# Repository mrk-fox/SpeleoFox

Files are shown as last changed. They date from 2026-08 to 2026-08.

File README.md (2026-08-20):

<div align="center">
<h1>SpeleoFox</h1><br>
  
A Speleology headlamp - engineered for the caves 

 


<br>

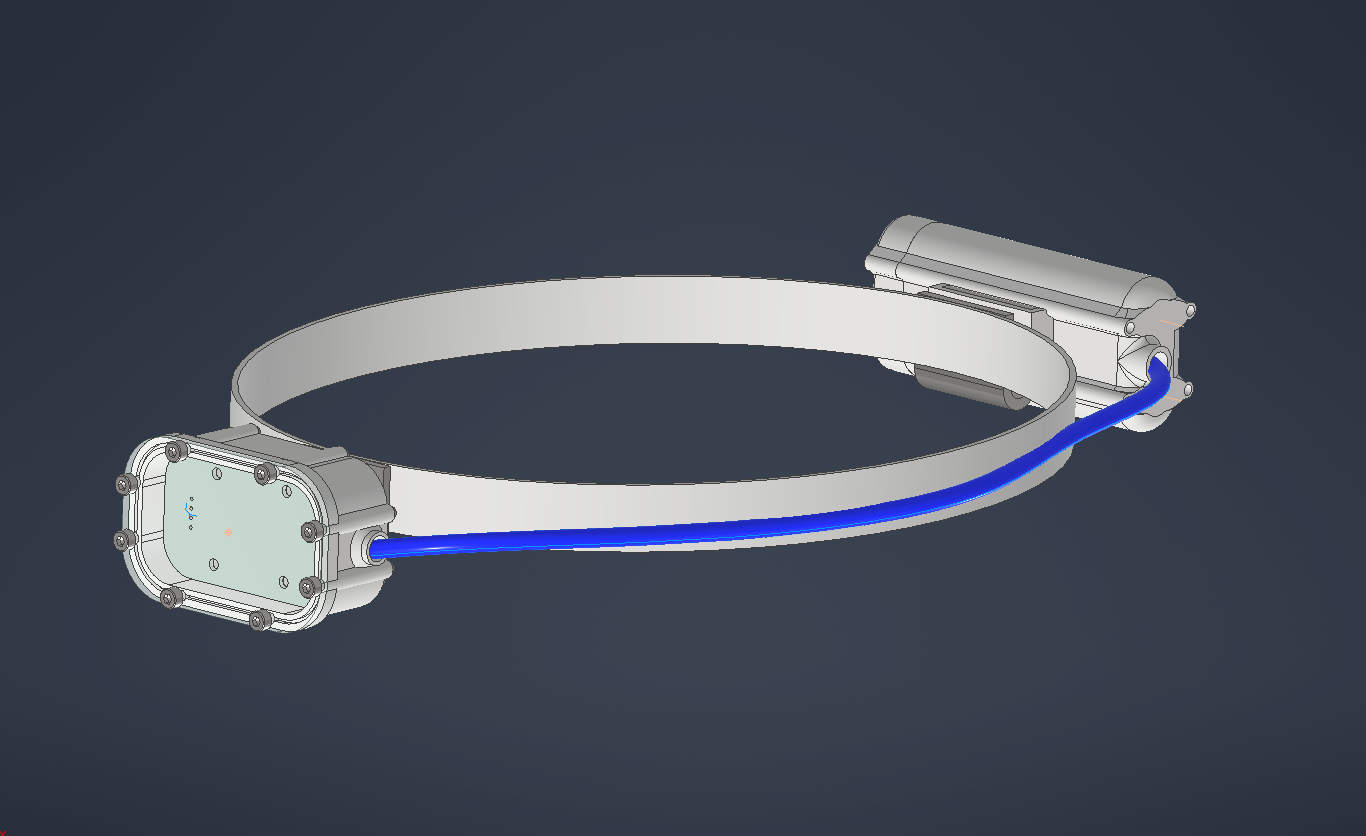
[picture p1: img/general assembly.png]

<div align="left">v0.1</div>
</div>

SpeleoFox is a DIY helmet-mounted headlamp, designed for caving activities.

> [!WARNING]
> **Early hardware revision.** SpeleoFox has not been manufactured or tested yet. The board is currently waiting on funding before manufacturing.

## Preliminiaries 
Light in caves is more than just an "aid to see". Its a guarantee of surviviability and situation awareness, which results, when abscent, in fatal situations requiring specialised teams for rescue opertions. Caves are natuarally a hostile environment for humans, where moisture and rough, abrasive condition in movement force equipment to reach its limit. Therefore, already since the earliest XXth century, rugged caving and mining headlamps were basic equipment for cavers and miners. Since then LED's (Light Emitting Diodes) reached consumer market electronics making portable light sorces more efficient than ever before. Even though once basic eqipment of some countires 30% of poulation, caving and mining headlams are bound to a high price beginning from 250€. Therefore, this project aimed to create a simple and cheap, yet withstanding, piece of lighting equipment suitable for caving. 

## Features

- Simple, fail-proof electronics
- Modularity and ease of repare
- One led with two lighting modes to cover a variety of situations underground
- Waterproof case
- 2x 18650 Batteries (With protetion!) on the back side of the helmet

## PCB
The PCB features a AMS1117-2.5 controller for the LED intensity regulator and an AL8860 LED Regulator IC

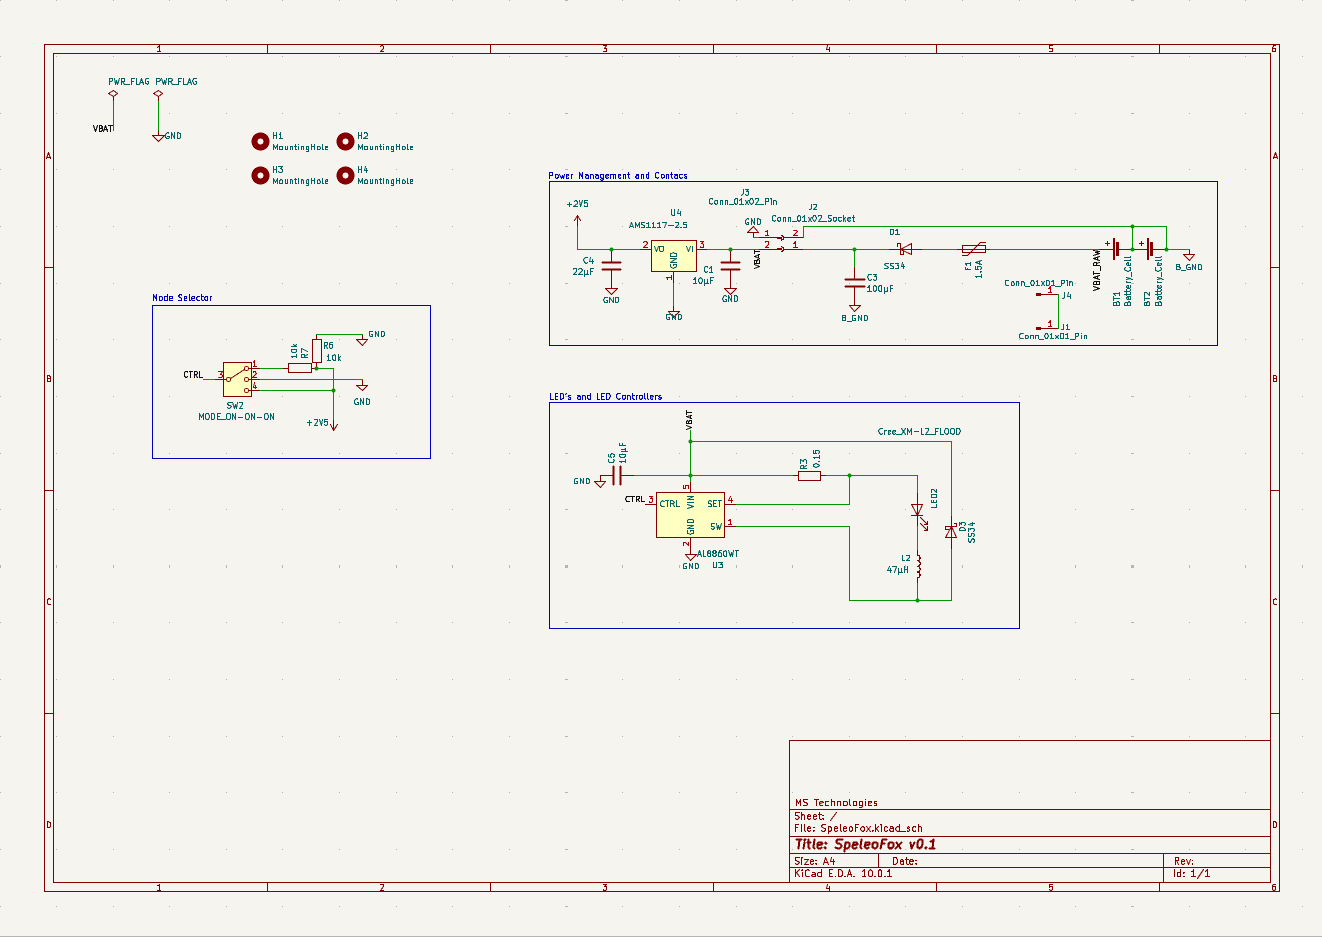
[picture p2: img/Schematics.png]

<div align="left">PCB Schematic</div>

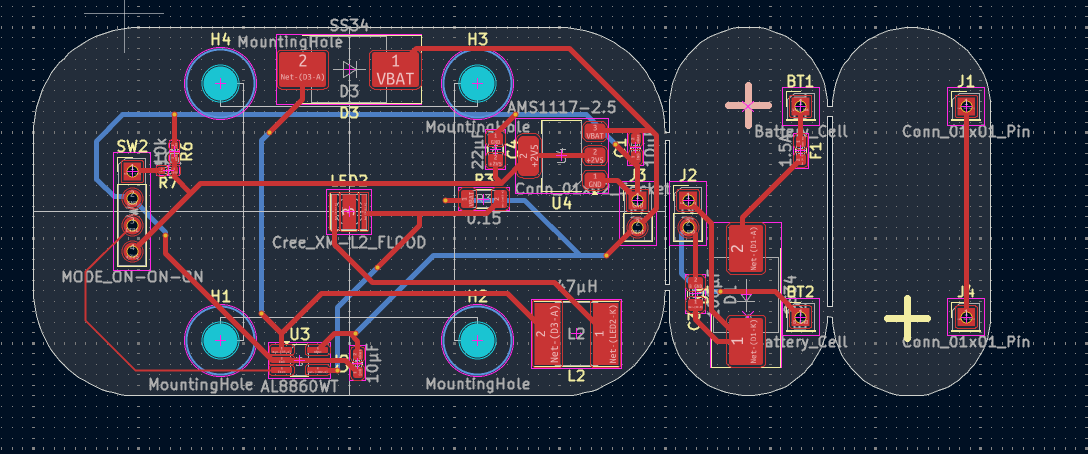
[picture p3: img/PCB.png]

<div align="left">PCB Layers</div>

## CAD

The main maxime while designing the CAD for this project was the goal to protect the electronics on the inside from the harsh conditions in the cave. The thorough documentation can be found in the JOURNAL.md file in this repository.
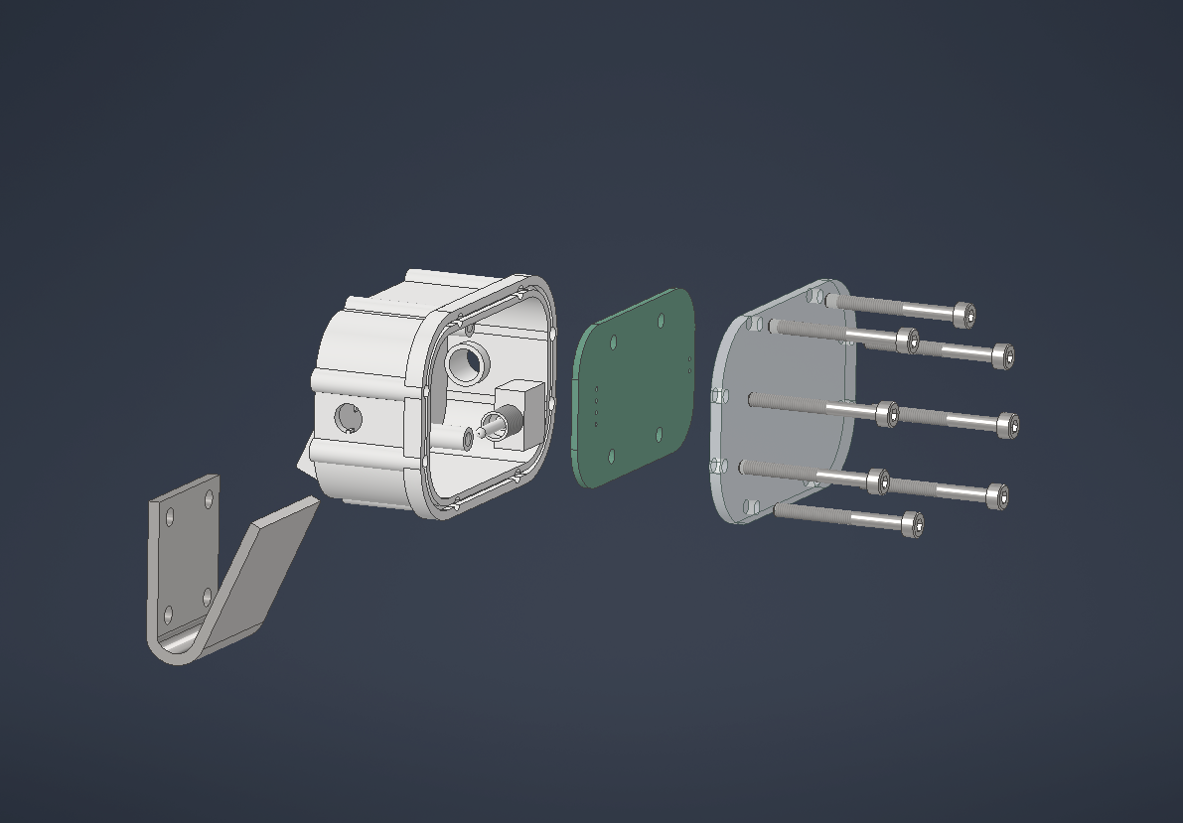
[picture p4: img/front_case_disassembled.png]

<div align="left">Front (Emitting) Part disassembled</div>

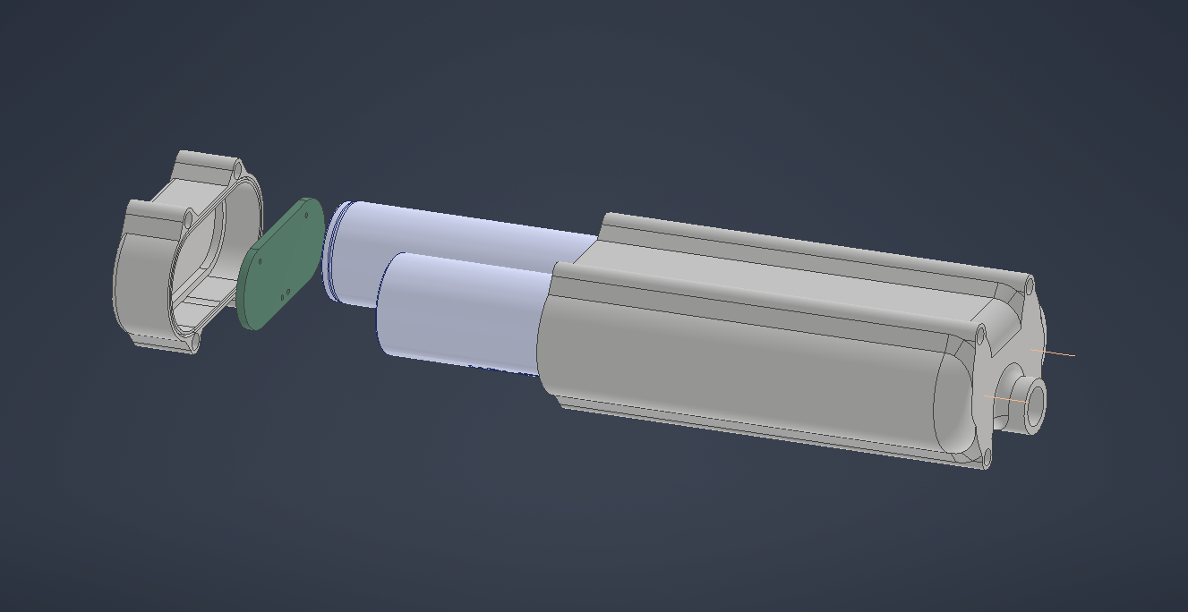
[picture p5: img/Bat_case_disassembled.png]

<div align="left">Backside (Battery) Part disassembled</div>

## Assembly

1. First, prepare the PCB by de-panelizing it and soldering all the components according to the BOM, Schematic and PCB Layer (Dont forget to connect the PCBs with a long enoug cable with each other)
2. Print the components in PETG
3. Thermalglue the Radiator to the backside of the LED PCB
4. Place the PCBs into the Printed components
5. Cut a piece of Plexiglass into place and drill holes at the right placec according to the printed part.
6. Use sealant to place the Lids/Plexi onto the 3d printed components after inserting the Batteries
7. Use sealant to seal the cable outlets
8. Screw the components togerther, wait till the sealant dries out and go caving!

## Happy Caving! Please be careful! I thank:
- HACK CLUB
- Kai the Jolly Guy
- Everyone who participated in the 48 hours hackathon!

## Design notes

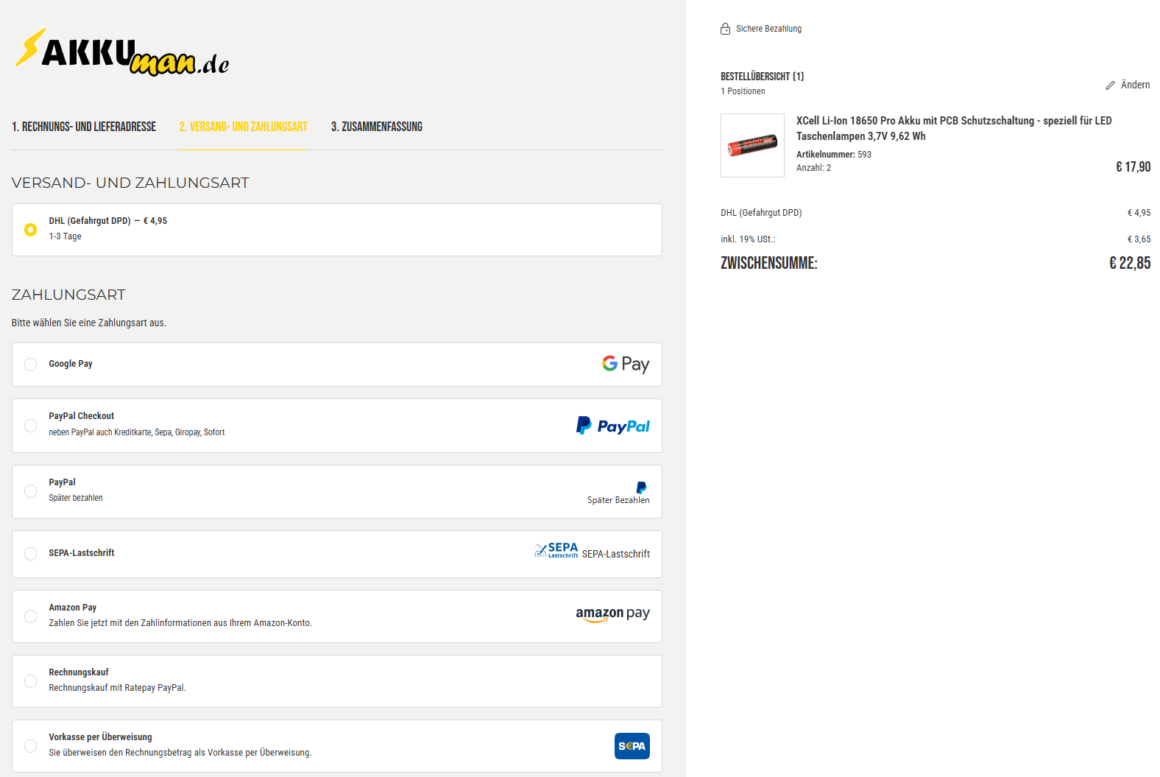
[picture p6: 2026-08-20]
img/AkkuMan.png

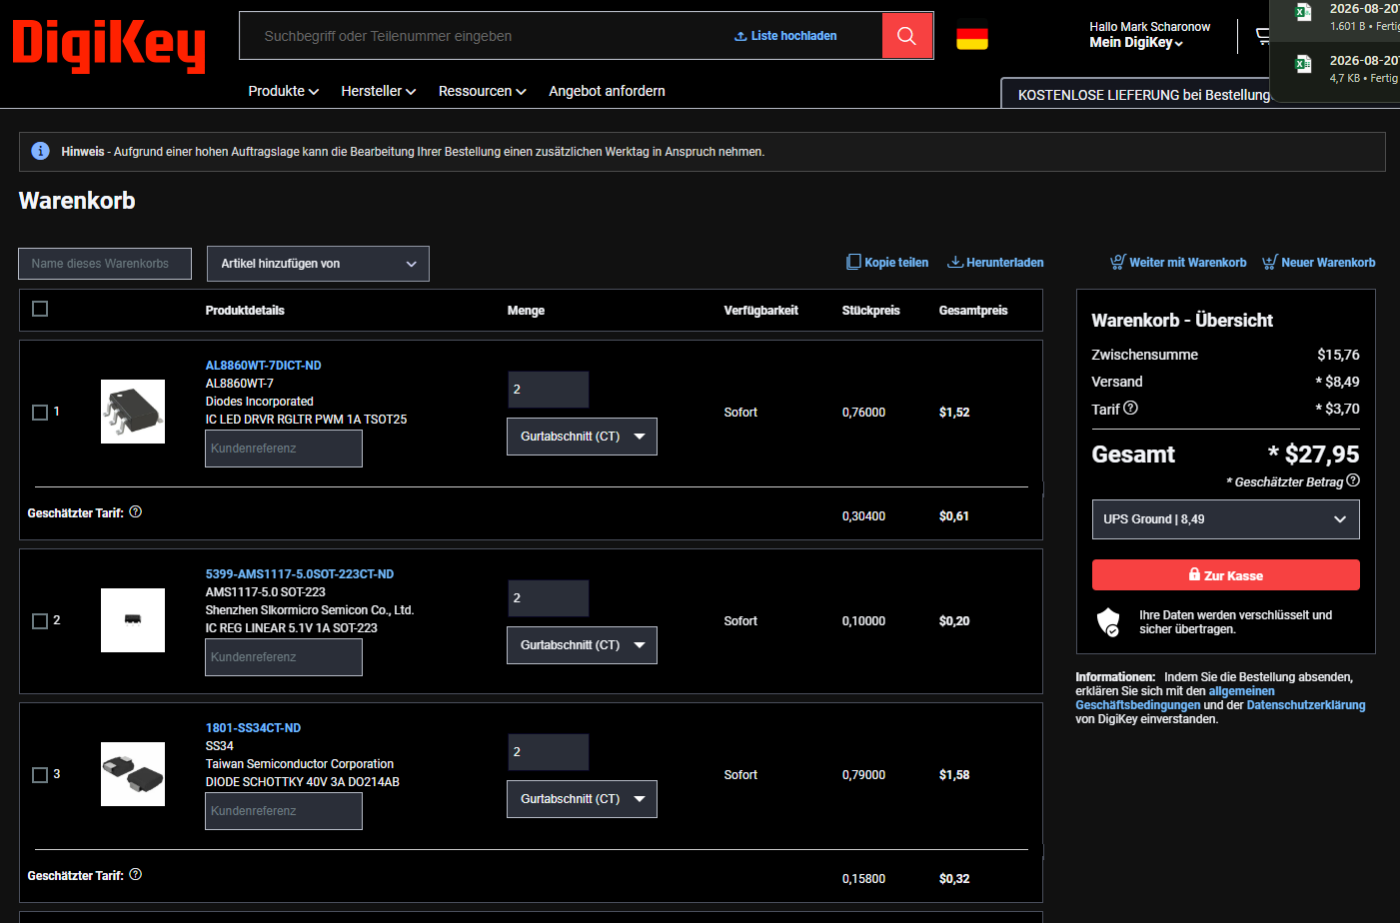
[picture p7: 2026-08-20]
img/DigiKey.png

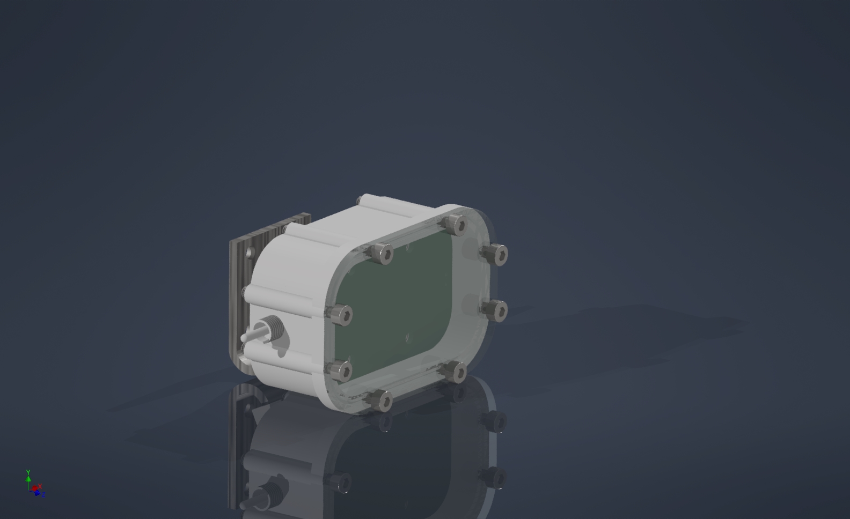
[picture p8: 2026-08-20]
img/SpeleoFox_front.jpg

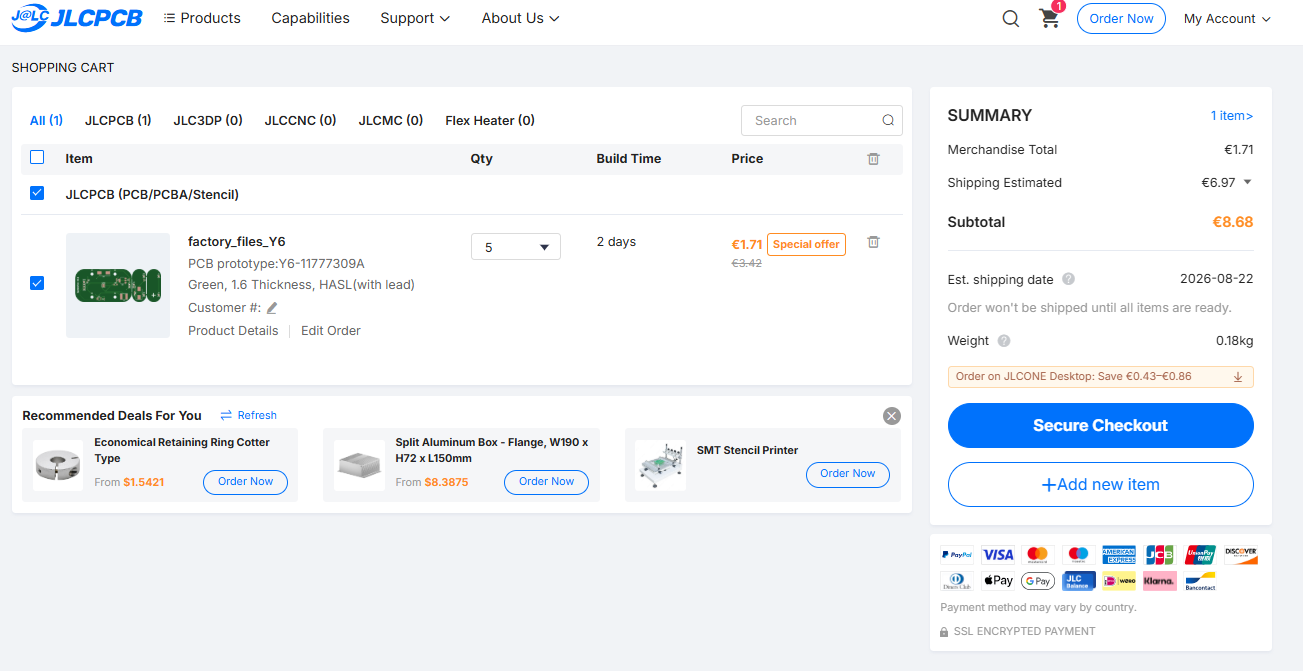
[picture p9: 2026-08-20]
img/JLCPCB.png

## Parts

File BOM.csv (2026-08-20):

Index | Amount | Part Number | Vendor | Description | Price PP | USD Price
1 | 2 | AL8860WT-7DICT-ND | DigiKey | IC LED DRVR RGLTR PWM 1A TSOT25 | 0,76000 | $1,52
2 | 2 | 5399-AMS1117-5.0SOT-223CT-ND | DigiKey | IC REG LINEAR 5.1V 1A SOT-223 | 0,10000 | $0,20
3 | 2 | 1801-SS34CT-ND | DigiKey | DIODE SCHOTTKY 40V 3A DO214AB | 0,79000 | $1,58
4 | 2 | 5923-C2Q1.5CT-ND | DigiKey | FUSE BRD MT 1.5A 32VAC 63VDC | 0,42000 | $0,84
5 | 2 | 490-12389-1-ND | DigiKey | CAP CER 22UF 25V X5R 0805 | 0,48000 | $0,96
6 | 2 | 587-2942-1-ND | DigiKey | FIXED IND 47UH 920MA 390 MOHM | 0,26000 | $0,52
7 | 2 | 273-KDV12FR150ETCT-ND | DigiKey | RES 0.15 OHM 1% 1/2W 1206 | 0,22000 | $0,44
8 | 10 | RMCF0402FT10K0CT-ND | DigiKey | RES 10K OHM 1% 1/16W 0402 | 0,02000 | $0,20
9 | 2 | 490-13981-1-ND | DigiKey | CAP CER 100UF 6.3V X5R 0805 | 0,99000 | $1,98
10 | 1 | 2223-HSB07-202009-ND | DigiKey | HEAT SINK, BGA, 20 X 20 X 9 MM | 0,93000 | $0,93
11 | 3 | 490-12317-1-ND | DigiKey | CAP CER 10UF 16V X5R 0603 | 0,29000 | $0,87
12 | 2 | XPGDWT-B1-0000-00LE5CT-ND | DigiKey | LED XLAMP NEUTRAL WHT 4000K SMD | 1,02000 | $2,04
13 | 1 | 2449-AST13SEBQ-ND | DigiKey | SWITCH TOGGLE SPDT 5A 120V | 3,68000 | $3,68
14 | 1 | N/A | DigiKey | Delivery |  | $8.49
15 | 1 | N/A | DigiKey | Tariffs |  | $3.70
16 | 5 | SpeleoFox v0.1 | JLCPCB | PCB | 8,68000 | $8.68
17 | 2 | 18650 Batteries w/ prot. | AkkuMan | Batteries | 8,95000 | $22.85
 |  |  |  | Total |  | $59.48

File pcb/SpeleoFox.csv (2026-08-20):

Reference | Qty | Value | DNP | Exclude from BOM | Exclude from Board | Footprint | Datasheet
BT1,BT2 | 2 | Battery_Cell
C1,C2,C5,C6 | 4 | 10µF |  |  |  | 1206 | https://www.digikey.de/de/products/detail/samsung-electro-mechanics/CL31B106KBHNNNE/5961251
C3 | 1 | 100µF |  |  |  | 1206 | https://www.digikey.de/de/products/detail/murata-electronics/GRM31CR61A107MEA8L/16033775
C4 | 1 | 22µF |  |  |  | 0805 | https://www.digikey.de/de/products/detail/murata-electronics/GRM21BZ71A226ME15L/13904953
C7 | 1 | 1µF |  |  |  | 0603 | https://www.digikey.de/de/products/detail/samsung-electro-mechanics/CL10B105KA8NNNC/3886842
D1,D3,D5 | 3 | SS34 |  |  |  |  | https://www.digikey.de/de/products/detail/onsemi/SS34/1052384
D4 | 1 | LED_Dual_AAKK |  |  |  | 3x2.54 | https://www.digikey.de/de/products/detail/kingbright/WP59SURKSGC/25807463
F1 | 1 | 1A |  |  |  | 0603 | https://www.digikey.de/de/products/detail/vishay/MFU0603FF01000P500/1202604
J1 | 1 | UPDI |  |  |  | 3x2.54
J2 | 1 | Conn_01x02_Socket |  |  |  | 2x2.54
J3 | 1 | Conn_01x02_Pin |  |  |  | 2x2.54
L2,L3 | 2 | 47µH |  |  |  | 0603 | https://www.digikey.de/de/products/detail/taiyo-yuden/CBMF1608T470K/1007996
LED1 | 1 | Cree_XP-L_HI_SPOT_focused-lens |  |  |  | Cree XP-L | https://www.digikey.de/de/products/detail/cree-led/XPLAWT-H0-0000-0000V2051/5303741
LED2 | 1 | Cree_XM-L2_FLOOD |  |  |  | Cree XP-G
R3,R4 | 2 | 0.15 |  |  |  | 0603 | https://www.digikey.de/de/products/detail/vishay-dale/RCWE0603R150FKEA/2276451
R5,R12,R14 | 3 | 470 |  |  |  | 0603 | https://www.digikey.de/de/products/detail/vishay-dale/CRCW0603470RFKEA/1174630
R6,R7,R8,R9 | 4 | 10k |  |  |  | 0603 | https://www.digikey.de/de/products/detail/vishay-dale/CRCW060310K0FKEA/1174782
R10,R11 | 2 | 100k |  |  |  | 0603 | https://www.digikey.de/de/products/detail/vishay-dale/CRCW0603100KFKEA/1174896
RT1 | 1 | 10k_NTC |  |  |  | 2x2.54 | https://www.digikey.de/de/products/detail/eaton-electronics-division/NRBE104F3435B2F/15927749
SW1 | 1 | PWR_ON_OFF |  |  |  | 2x2.54
SW2 | 1 | MODE_ON-ON-ON |  |  |  | 4x2.25
U1 | 1 | ATtiny1616-S |  |  |  | 20-SOIC | https://www.digikey.de/de/products/detail/microchip-technology/ATTINY1616-SN/10231345
U3,U5 | 2 | AL8860WT |  |  |  | TSOT-25 | https://www.digikey.de/de/products/detail/diodes-incorporated/AL8860WT-7/6226978
U4 | 1 | AMS1117-5.0 |  |  |  | SOT-223 | https://www.digikey.de/de/products/detail/shenzhen-slkormicro-semicon-co-ltd/AMS1117-5-0-SOT-223/22204997

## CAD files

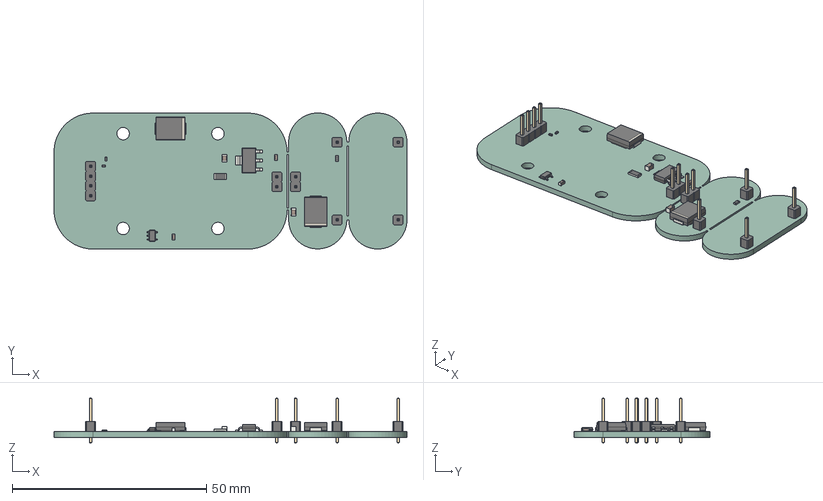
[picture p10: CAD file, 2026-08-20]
cad/Speleofox PCB.step
90.9 x 35.0 x 11.5 mm
TSOT-23-5
D_SMC x 2
R_0402_1005Metric x 2
PinHeader_1x01_P2.54mm_Vertical x 4
C_0603_1608Metric x 2
PinHeader_1x02_P2.54mm_Vertical x 2
R_1206_3216Metric
Fuse_0603_1608Metric
SOT-223
PinHeader_1x04_P2.54mm_Vertical
C_0805_2012Metric x 2
SpeleoFox_PCB

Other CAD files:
cad/OldVersions/SpeleoFox.0001.iam
cad/SpeleoFox.iam
cad/SpeleoFox/AIP/Cable and Harness/SpeleoFox.Harness1.iam
cad/SpeleoFox/AIP/Cable and Harness/SpeleoFox.Harness1.ipt
cad/assets/18650 Battery.ipt
cad/assets/OldVersions/battery_case_shell.0002.ipt
cad/assets/battery_case_shell.ipt
cad/speleofox_parts/AST13SEBQ.ipt
cad/speleofox_parts/BAT_speleopcb_part.ipt
cad/speleofox_parts/C_0603_1608Metric.ipt
cad/speleofox_parts/C_0805_2012Metric.ipt
cad/speleofox_parts/D_SMC.ipt
cad/speleofox_parts/Fuse_0603_1608Metric.ipt
cad/speleofox_parts/LED_speleopcb_part.ipt
cad/speleofox_parts/OldVersions/LED_speleopcb_part.0001.ipt
cad/speleofox_parts/OldVersions/SpeleoFox_PCB.0001.ipt
cad/speleofox_parts/OldVersions/SpeleoFox_front.0003.iam
cad/speleofox_parts/OldVersions/back_assembly.0002.iam
cad/speleofox_parts/OldVersions/battery_case_top.0001.ipt
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

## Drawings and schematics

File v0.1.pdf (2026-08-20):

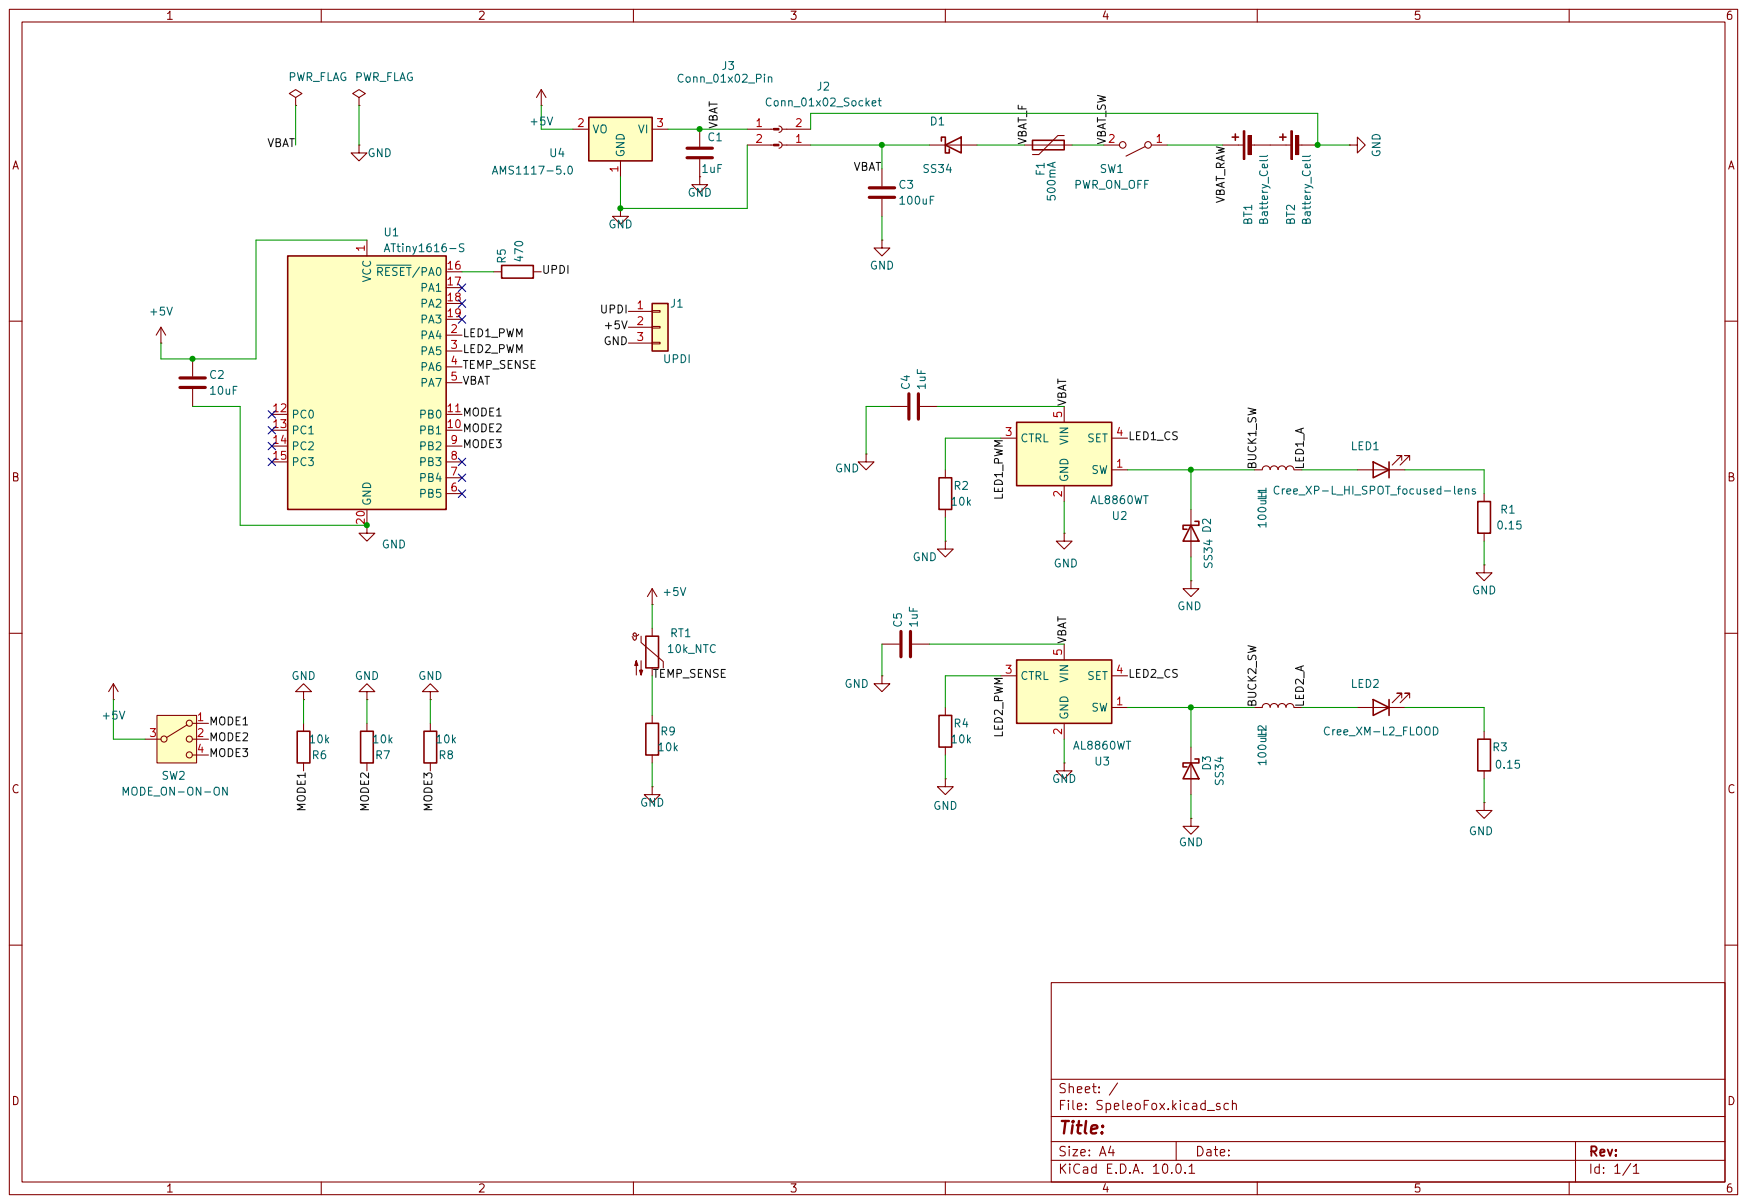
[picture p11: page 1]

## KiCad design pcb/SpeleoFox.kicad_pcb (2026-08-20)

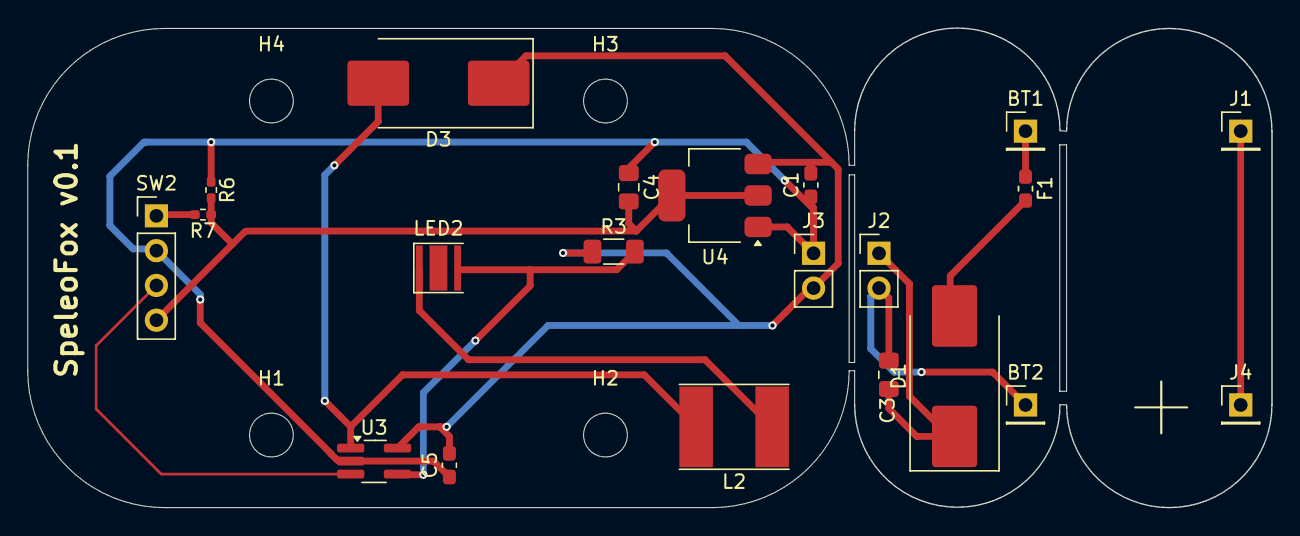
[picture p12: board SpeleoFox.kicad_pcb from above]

Board: 2 copper layers, 90.9 x 35.0 mm, 25 parts (0 on the bottom side), 13 nets.

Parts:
BT1, BT2: Battery_Cell; PinHeader_1x01_P2.54mm_Vertical
C1, C5: 10µF; C_0603_1608Metric_Pad1.08x0.95mm_HandSolder
C3: 100µF; C_0805_2012Metric_Pad1.18x1.45mm_HandSolder
C4: 22µF; C_0805_2012Metric_Pad1.18x1.45mm_HandSolder
D1, D3: SS34; D_SMC_Handsoldering
F1: 1.5A; Fuse_0603_1608Metric_Pad1.05x0.95mm_HandSolder
H1, H2, H3, H4: MountingHole; MountingHole_3.2mm_M3
J1, J4: Conn_01x01_Pin; PinHeader_1x01_P2.54mm_Vertical
J2: Conn_01x02_Socket; PinHeader_1x02_P2.54mm_Vertical
J3: Conn_01x02_Pin; PinHeader_1x02_P2.54mm_Vertical
L2: 47µH; L_Taiyo-Yuden_NR-60xx_HandSoldering
LED2: Cree_XM-L2_FLOOD; LED_Cree-XP-G
R3: 0.15; R_1206_3216Metric_Pad1.30x1.75mm_HandSolder
R6, R7: 10k; R_0402_1005Metric_Pad0.72x0.64mm_HandSolder
SW2: MODE_ON-ON-ON; PinHeader_1x04_P2.54mm_Vertical
U3: AL8860WT; TSOT-23-5_HandSoldering
U4: AMS1117-2.5; SOT-223-3_TabPin2

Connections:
+2V5: C4.2, R6.2, R7.1, SW2.4, U4.2 (VO)
/CTRL: SW2.3, U3.3 (CTRL)
/VBAT: C1.2, C5.2, D3.1 (K), J3.2, R3.1, U3.5 (VIN), U4.3 (VI)
/VBAT_RAW: BT1.1 (+_1), F1.1
B_GND: BT2.1 (+_1), C3.2, J2.2
GND: C1.1, C4.1, C5.1, J3.1, R6.1, SW2.2, U3.2 (GND), U4.1 (GND)
unnamed: D1.2 (A), F1.2
unnamed: C3.1, D1.1 (K), J2.1
unnamed: D3.2 (A), L2.2, U3.1 (SW)
unnamed: J1.1 (Pin_1_1), J4.1 (Pin_1_1)
unnamed: LED2.2 (A), R3.2, U3.4 (SET)
unnamed: L2.1, LED2.1 (K)
unnamed: R7.2, SW2.1

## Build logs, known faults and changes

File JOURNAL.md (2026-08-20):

# Journal SpeleoFox

## Day 1

Today, primarily the following tasks were set and created: 

1. Define the goals of the Project
2. Define the basic architecture to achieve these goals
3. Refine these into a schematic strictly following the manufacturers datasheets
4. Refine the sheet into a ready PCB
5. Plan the Case and the features making it watertight.

For the first point, I decided to make a watertight, speleology grade headlamp mounting on my Edelrid helmet.

As the design is supped to function in caves, i decided to use a simplified approach feturing one CREE LED with an analouge controller instead of a multi LED ATtiny1616 controlled approach. 

At the end, this goal was approached by using a AMS1117-2.5 with a switch routing the current thorugh a 10kOhm volatage divider. The lamp was also deactivated with the AL8860 LED controlling IC. 

The PCB turned out to be a one-piece 3 component panel with a place for a heatsink on the backside to boost the power and supress overheat. 

https://github.com/mrk-fox/SpeleoFox/blob/main/img/PCB.png

The day took 13 hours building in total.

## Day 2

After the PCB was designed, the CAD part was the main focus of finishing the project. A bottom-sealed, screwed Plex lid was the main design idea for the front part, making the glass interchangable and the LEDs light dissipation unhindered. Also, the backside battery containter was designed in a similar way, both modues situated on a 30 mm wide, 3mm thick stainless mount screwed to the helmet. Also, the cable system featured a up to 6mm thick cable for enough isolation to prevent cable damage due to abrasion. The cable gets sealed to the body with my special sealant from Germany. 

Also, 3D printing isn't itself watertight. Therefore, I decided to design the case keeping an epoxidation in mind.

In the end, the final product featured a full, two-component assembly with a brim ring simulating the helmet and a cable as the connection between these two modules.

Total time spendings: 6 hours.

general assembly

Final assembly: Front and back parts (Emittor and Battery holder) on a stiff helmet ring

front_case_disassembled

Emitter disassembled. From left to right: helmet holder, case, mode select switch, emitter PCB, front glass, screws.

front_case_disassembledFinal 

PCB - Left side: Emittor PCB with Cree XM LED footprint in the middle, Battery connectors on the right side. Panelized.

journal entry: I spent another 2 hours documenting my work thoroughly.

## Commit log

2026-08-20 SpeleoFox v0.1
    [18650 Battery.ipt, AST13SEBQ.ipt, BAT_speleopcb_part.ipt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]
2026-08-20 Add BOM and journal; move helmet CAD file
    Add BOM.csv listing components, vendors and costs (includes delivery, tariffs, 5 PCBs and batteries; total $59.48). Add JOURNAL.md with Day 1/Day 2 development notes and link to PCB image. Move img/b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
    [BOM.csv, back_helmet_holder.ipt]

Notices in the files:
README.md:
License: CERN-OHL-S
